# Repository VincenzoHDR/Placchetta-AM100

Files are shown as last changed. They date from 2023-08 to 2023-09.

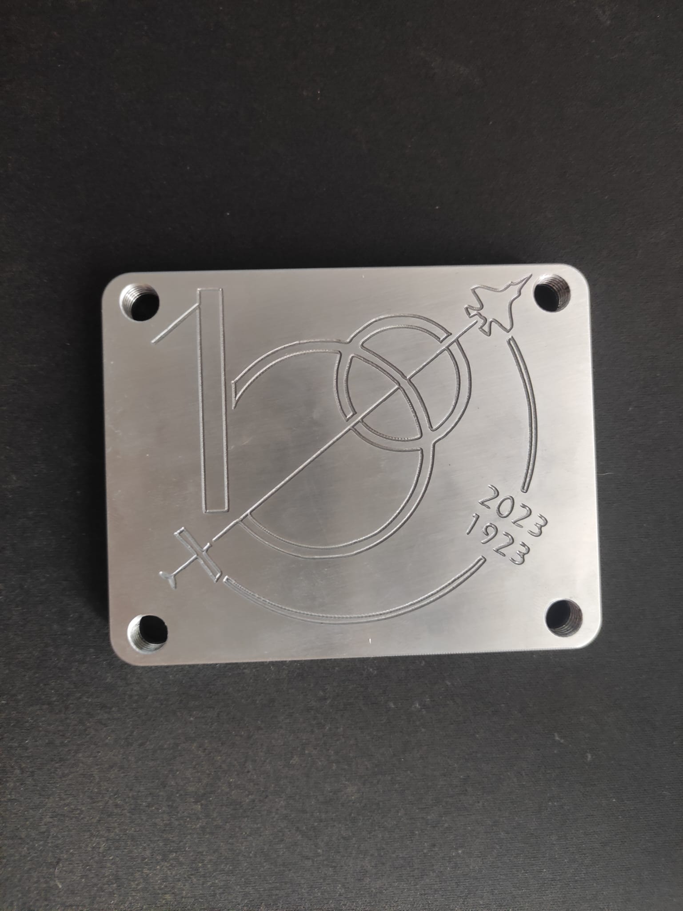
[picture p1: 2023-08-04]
Placchetta Finita/WhatsApp Image 2023-08-04 at 15.59.29 (1).jpeg

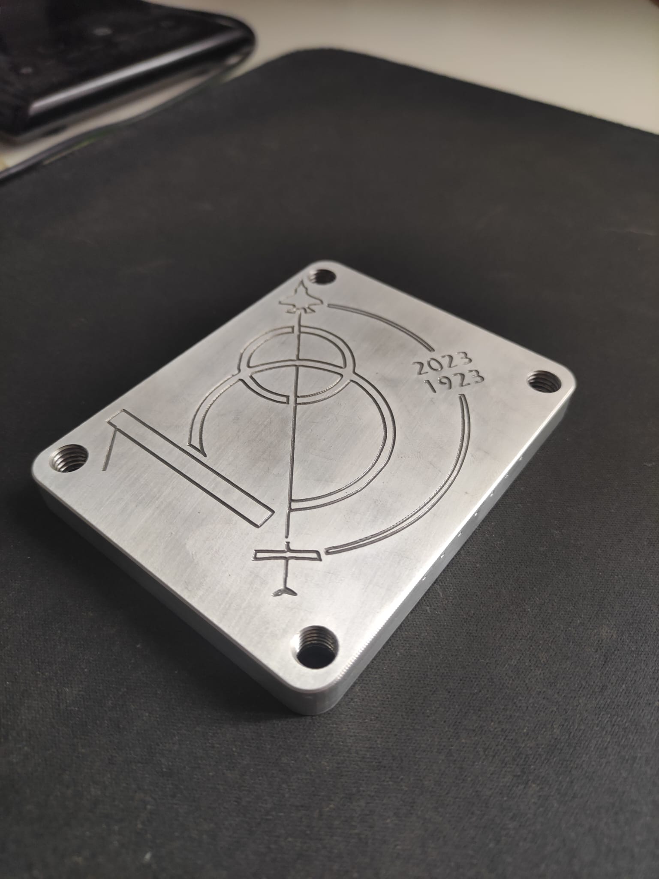
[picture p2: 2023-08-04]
Placchetta Finita/WhatsApp Image 2023-08-04 at 15.59.29 (2).jpeg

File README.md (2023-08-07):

# Placchetta-AM100
Produzione e Realizzazione placchetta commemorativa Centenario Aeronautica

Grezzo: 100mm x 80mm x 16mm

## UTENSILI

FASE1:

(T1 D=20. CR=0.4 - ZMIN=-0.9 - fresa)

(T2 D=12. CR=0. - ZMIN=-18. - Fresa cilindrica)

(T3 D=4. CR=0. TAPER=30deg - ZMIN=-1.05 - utensile per smusso)

(T4 D=6.8 CR=0. TAPER=118deg - ZMIN=-19.043 - Punta)

(T7 D=8. CR=0. TAPER=45deg - ZMIN=-2.5 - utensile per smusso)

(T8 D=8. CR=0. - ZMIN=-12. - right hand tap)

FASE2:

T1 D=20. CR=0.4 - ZMIN=-4.9 - fresa)

(T2 D=12. CR=0. - ZMIN=-12. - Fresa cilindrica)

(T7 D=8. CR=0. TAPER=45deg - ZMIN=-10. - utensile per smusso)

(T10 D=6. CR=3. - ZMIN=-11. - Ispezione)

# FASE 1

## PRESA IN MORSA

Cattura

## ORIGINE PEZZO 

L'origine del pezzo è stata ottenuta tramite i software presenti nel menù VPS delle macchine HAAS

## SPIANATURA

Rimozione 2mm superficiali lasciando 0.1mm di sovrametallo

Cattura

## SGROSSATURA E FINITURA PROFILO

Cattura

## RIMOZIONE MATERIALE GREZZO LATERALE

Cattura

## PREFORI M8

Cattura

## SMUSSATURA 0.5*45°

Cattura

## MASCHIATURA M8

Cattura

## INCISIONE LOGO CENTENARIO

Cattura

## FINITURA SUPERFICIALE

Cattura

Dopo la finitura è stato ritenuto necessario passare della carta vetrata fine al fine di rimuovere i segni lasciati del passaggio della fresa

# FASE 2

Al fine di rimuovere il materiale grezzo sottostante ed eseguire altre operazioni togliamo il pezzo dalla morsa e lo giriamo di 180°

## PRESA IN MORSA 

Cattura

## ORIGINE PEZZO

Sempre attraverso i software presenti nel menù VPS della macchina in utilizzo andiamo a creare una nuova origine sul materiale grezzo 

## SPIANATURA

Attivando passate multiple (2mm) andiamo a rimuovere il grezzo sottostante

Cattura

## ORIGINE PEZZO (Sul Finito)

Per ottenere una maggiore precisione nelle lavorazioni successive attraverso le funzioni di Fusion360 andiamo a creare una nuova origine sulla superficie del finito e poi sui lati

Cattura

Cattura

## RIMOZIONI DI BAVE LASCIATE DAL PROCESSO DI SPIANATURA

Cattura

## CREAZIONE DI DUE TASCHE CENTRALI

Il fine ultimo della creazione di queste due tasche è quello di ridurre il peso della placchetta



Le linee in rosso stanno ad indicare che la fresa sta lavorando con un movimento elicoidale

## FINITURA DELLE SUPERFICI

Rimozione dei sovrametalli

Cattura

## SMUSSATURA 0.5*45°

Cattura

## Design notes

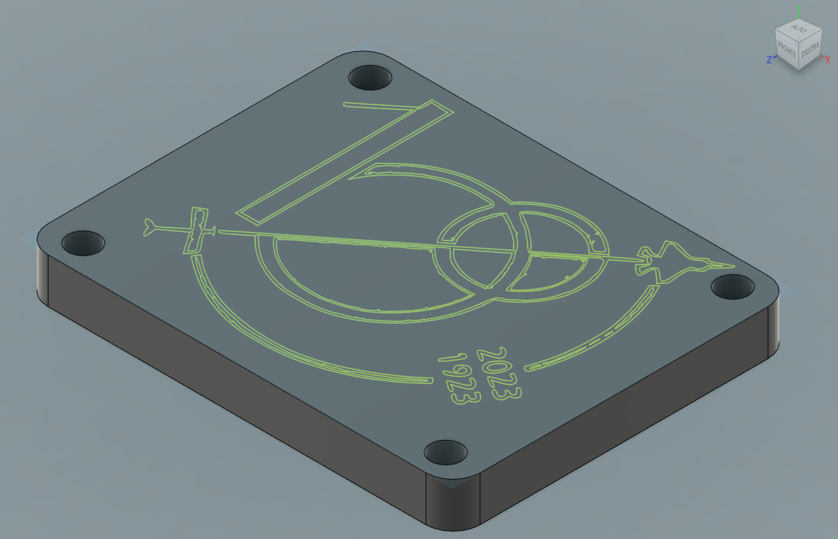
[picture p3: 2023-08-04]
Placchetta Finita Fusion 360/Cattura.PNG

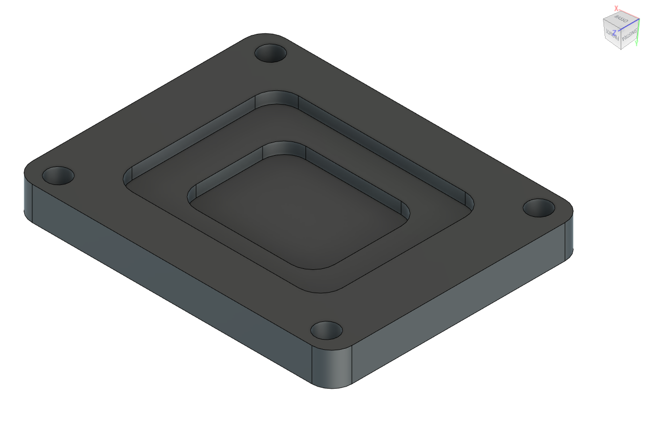
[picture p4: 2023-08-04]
Placchetta Finita Fusion 360/Cattura3.PNG

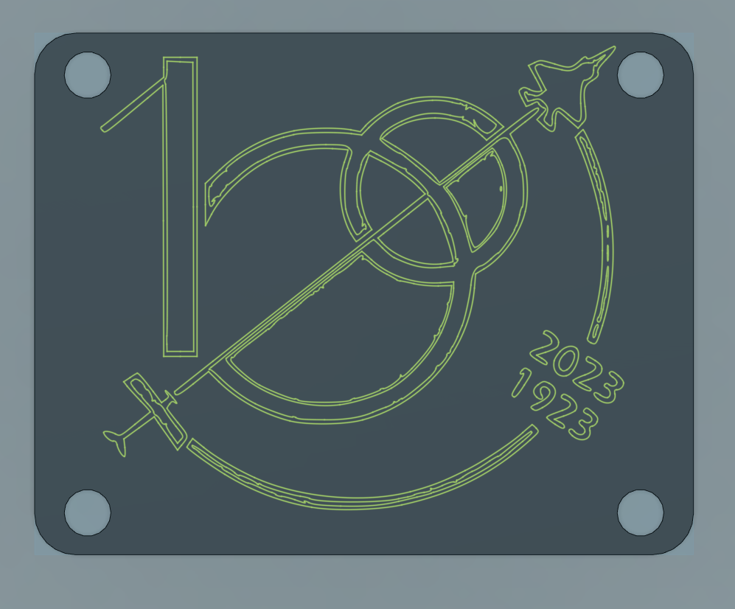
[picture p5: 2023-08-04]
Placchetta Finita Fusion 360/Cattura2.PNG

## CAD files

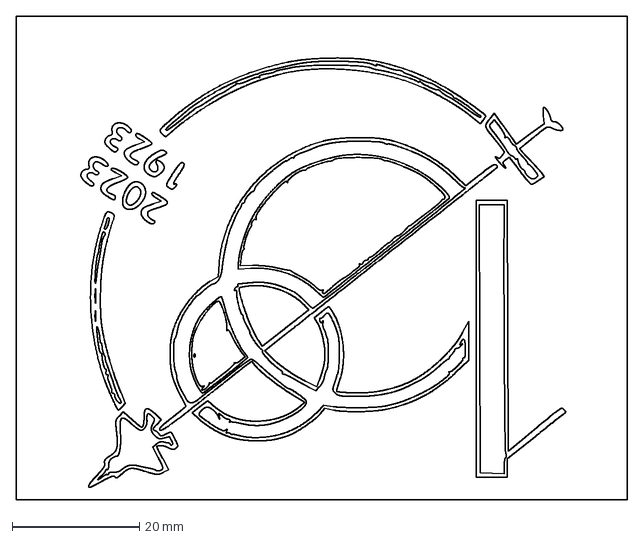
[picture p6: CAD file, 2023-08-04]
Sketch AM100.dxf
96.0 x 76.0 mm

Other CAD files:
100AM v8.f3d

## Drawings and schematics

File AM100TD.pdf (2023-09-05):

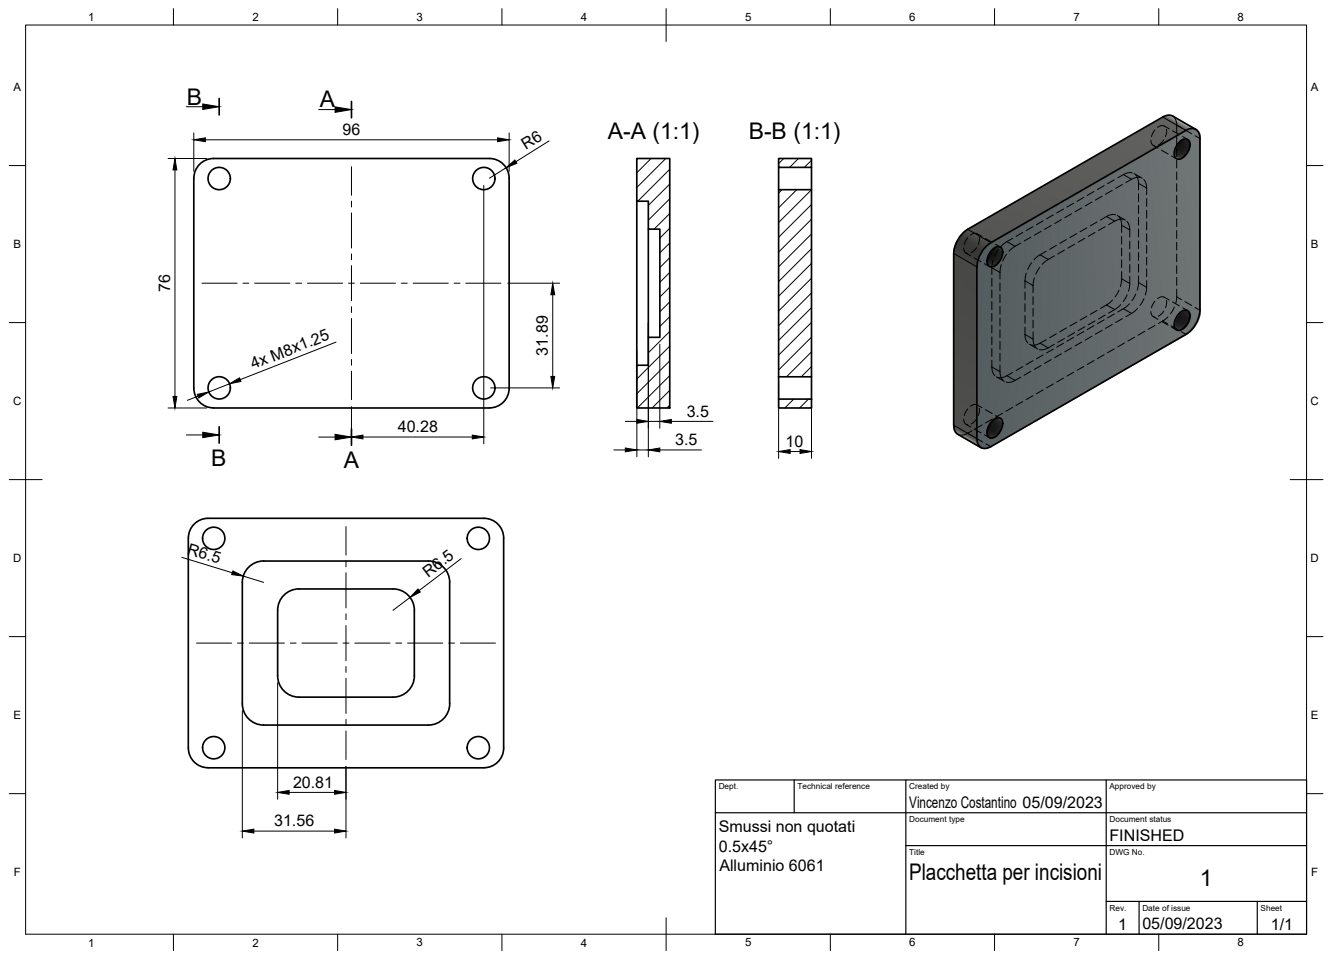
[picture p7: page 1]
Title; DWG No.; Rev.; Date of issue; Sheet; Placchetta per incisioni; Smussi non quotati; Alluminio 6061

Dept. | Technical reference | Created by Vincenzo Costantino 05/09/2023 | Approved by

Document type | Document status FINISHED
